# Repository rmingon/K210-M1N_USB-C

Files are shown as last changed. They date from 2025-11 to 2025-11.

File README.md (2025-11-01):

# K210-M1N USB-C Adapter

This repository contains the KiCad 9 project for a compact adapter board that breaks out the **Kendryte K210 M1n** M.2 (Key‑B) module to USB and a minimal set of GPIOs. The board’s USB‑C port is intended primarily for power and UART-based programming through an onboard CH340C USB–serial bridge.

## Hardware Overview

- **Form factor** – Single board implementing the Amphenol MDT320B03001 Key‑B M.2 socket on the top side and a USB‑C receptacle on the edge for direct plug-in to a host.
- **Power** – USB VBUS feeds the CH340C (`+5V`) and is decoupled locally (C9). The board relies on the M1n module’s onboard regulators for `+3.3V` and `+1V8`.
- **USB–UART** – CH340C in SOIC‑16 package with `D+`/`D-` routed to the USB‑C connector and a BOOT/RESET autoprogramming network (R7 to BOOT, R8 to RESET).
- **Status LEDs** – Two LEDs (D1/D2) with current-limiting resistors (R3/R4) monitor `+5V` and `VBUS`.
- **Breakout signals** – Key M.2 pins (IO, SPI0, DVP, etc.) are accessible via the module connector. The schematic uses global labels (`IO4`, `IO5`, …) matching Kendryte’s numbering.

### Board visuals

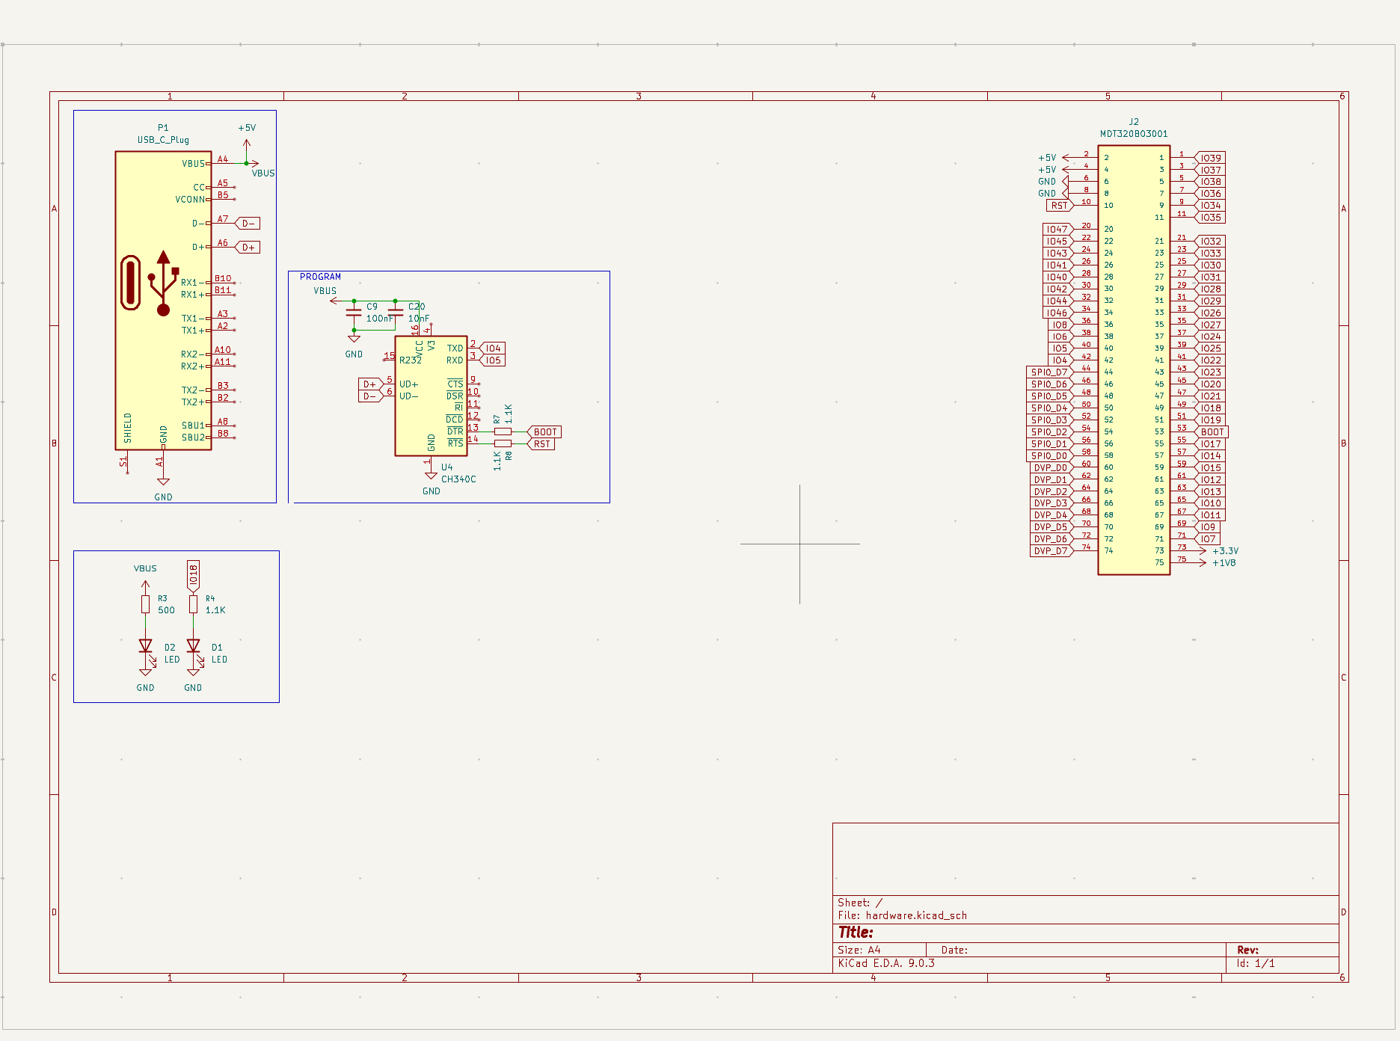
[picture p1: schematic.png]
Schematic overview


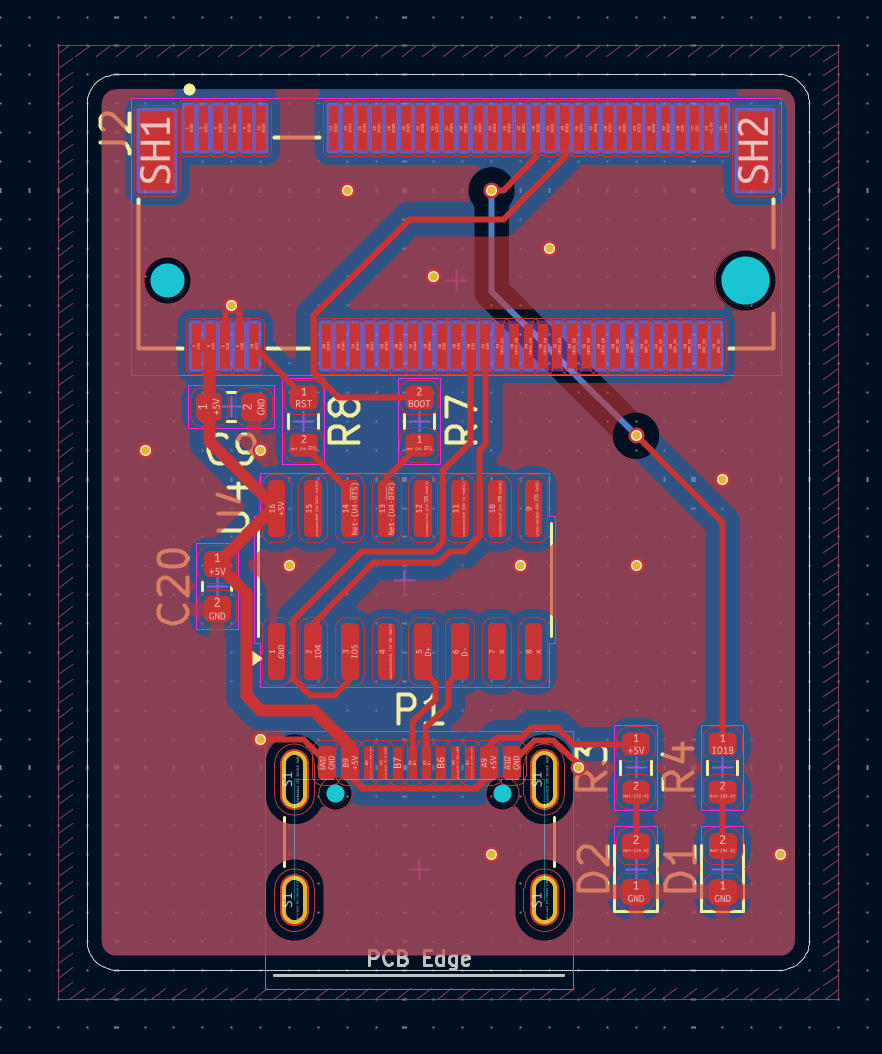
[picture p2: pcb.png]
Layout top view


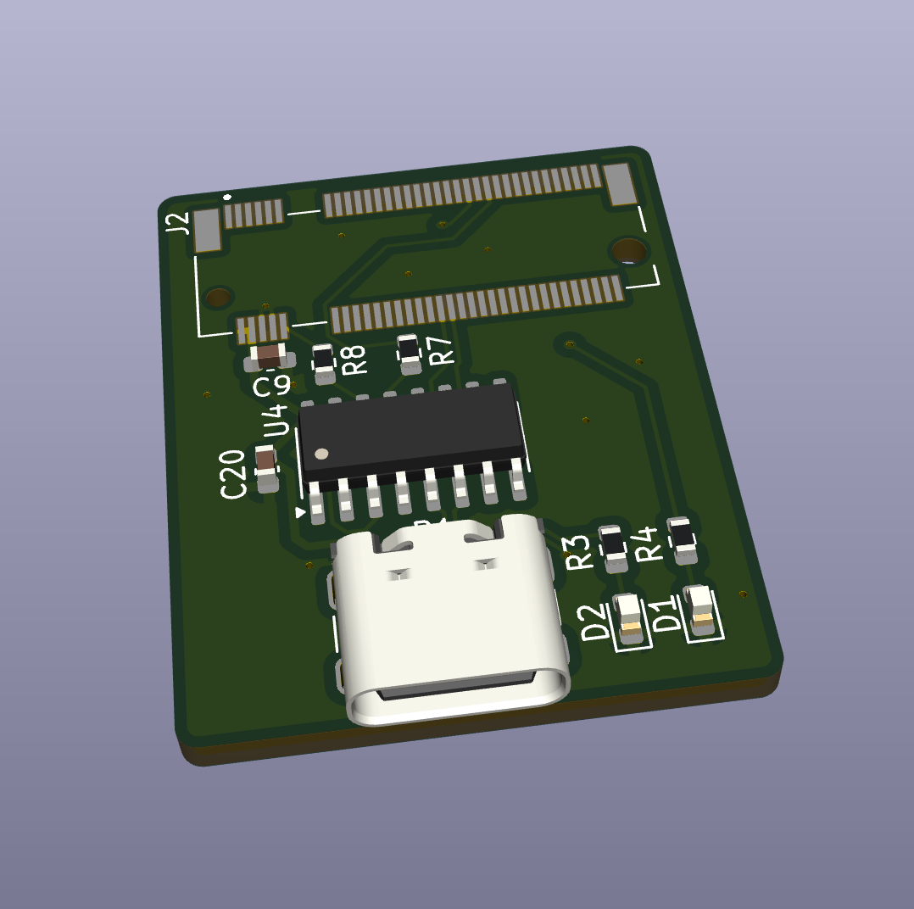
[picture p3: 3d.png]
3D render


## Programming Workflow

- The CH340C exposes a UART for flashing firmware onto the K210 module.
- `~RTS` is routed through R8 to the `RST` net (M.2 pad 10), while `~DTR` drives the `BOOT` net (M.2 pad 53) via R7 to automate the boot sequence used by Kendryte tooling.
- Connect the USB‑C port to your host PC, install CH340 drivers if needed, and use Kendryte’s flashing tools over the enumerated serial port.

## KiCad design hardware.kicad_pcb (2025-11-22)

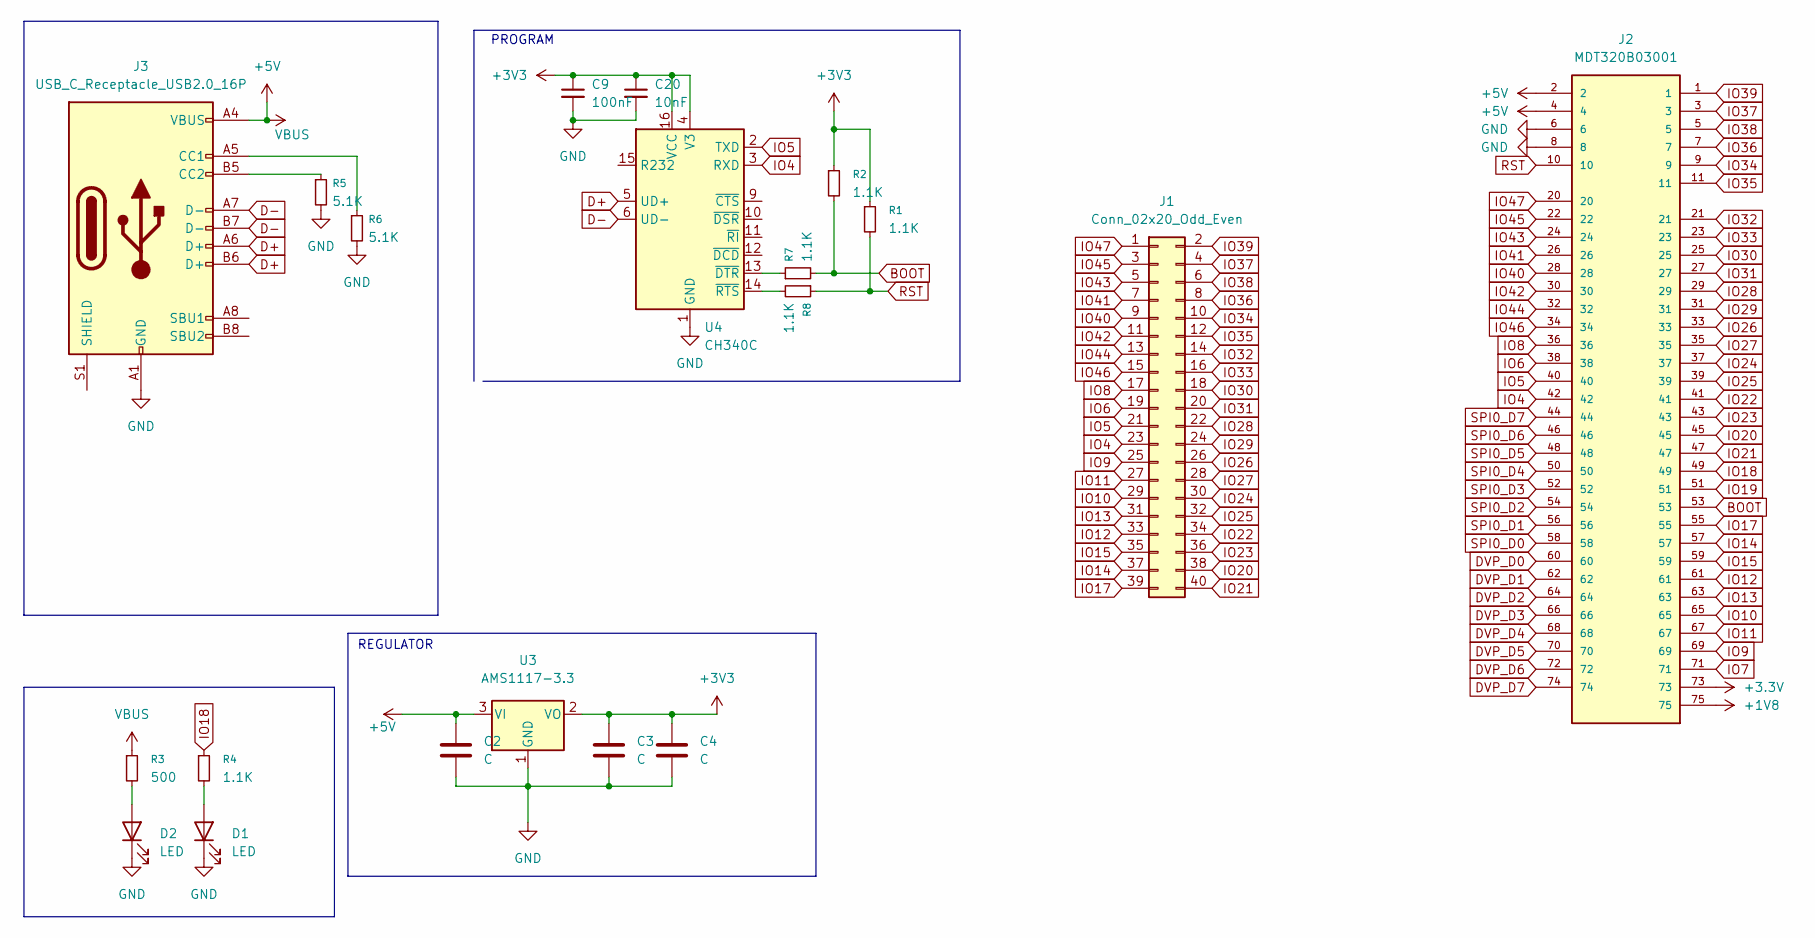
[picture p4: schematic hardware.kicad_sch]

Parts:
C2, C4: C; C_0603_1608Metric; LCSC C30926
C3: C; C_0603_1608Metric; LCSC C19702
C9: 100nF; C_0603_1608Metric
C20: 10nF; C_0603_1608Metric
D1, D2: LED; LED_0603_1608Metric
J1: Conn_02x20_Odd_Even; IDC-Header_2x20_P2.54mm_Horizontal
J2: MDT320B03001; AMPHENOL_MDT320B03001; PARTREV 4
J3: USB_C_Receptacle_USB2.0_16P
R1, R2, R4, R7, R8: 1.1K; R_0603_1608Metric
R3: 500; R_0603_1608Metric
R5, R6: 5.1K; R_0603_1608Metric
U3: AMS1117-3.3; SOT-223-3_TabPin2; LCSC C6186
U4: CH340C; SOIC-16_3.9x9.9mm_P1.27mm

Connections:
+1V8: J2.75
+3.3V: J2.73
+3V3: C3.1, C4.1, C9.1, C20.1, R1.1, R2.1, U3.2 (VO), U4.4 (V3), U4.16 (VCC)
+5V: C2.1, J2.2, J2.4, J3.A4 (VBUS), J3.A9 (VBUS), J3.B4 (VBUS), J3.B9 (VBUS), R3.1, U3.3 (VI)
BOOT: J2.53, R2.2, R7.2
D+: J3.A6 (D+), J3.B6 (D+), U4.5 (UD+)
D-: J3.A7 (D-), J3.B7 (D-), U4.6 (UD-)
DVP_D0: J2.60
DVP_D1: J2.62
DVP_D2: J2.64
DVP_D3: J2.66
DVP_D4: J2.68
DVP_D5: J2.70
DVP_D6: J2.72
DVP_D7: J2.74
GND: C2.2, C3.2, C4.2, C9.2, C20.2, D1.1 (K), D2.1 (K), J2.6, J2.8, J3.A1 (GND), J3.A12 (GND), J3.B1 (GND), J3.B12 (GND), R5.2, R6.2, U3.1 (GND), U4.1 (GND)
IO4: J1.23, J2.42, U4.3 (RXD)
IO5: J1.21, J2.40, U4.2 (TXD)
IO6: J1.19, J2.38
IO7: J2.71
IO8: J1.17, J2.36
IO9: J1.25, J2.69
IO10: J1.29, J2.65
IO11: J1.27, J2.67
IO12: J1.33, J2.61
IO13: J1.31, J2.63
IO14: J1.37, J2.57
IO15: J1.35, J2.59
IO17: J1.39, J2.55
IO18: J2.49, R4.1
IO19: J2.51
IO20: J1.38, J2.45
IO21: J1.40, J2.47
IO22: J1.34, J2.41
IO23: J1.36, J2.43
IO24: J1.30, J2.37
IO25: J1.32, J2.39
IO26: J1.26, J2.33
IO27: J1.28, J2.35
IO28: J1.22, J2.29
IO29: J1.24, J2.31
IO30: J1.18, J2.25
IO31: J1.20, J2.27
IO32: J1.14, J2.21
IO33: J1.16, J2.23
IO34: J1.10, J2.9
IO35: J1.12, J2.11
IO36: J1.8, J2.7
IO37: J1.4, J2.3
IO38: J1.6, J2.5
IO39: J1.2, J2.1
IO40: J1.9, J2.28
IO41: J1.7, J2.26
IO42: J1.11, J2.30
IO43: J1.5, J2.24
IO44: J1.13, J2.32
IO45: J1.3, J2.22
IO46: J1.15, J2.34
IO47: J1.1, J2.20
unnamed: D1.2 (A), R4.2
unnamed: D2.2 (A), R3.2
unnamed: J3.A5 (CC1), R6.1
unnamed: J3.B5 (CC2), R5.1
unnamed: R7.1, U4.13 (~DTR)
unnamed: R8.2, U4.14 (~RTS)
RST: J2.10, R1.2, R8.1
SPI0_D0: J2.58
SPI0_D1: J2.56
SPI0_D2: J2.54
SPI0_D3: J2.52
SPI0_D4: J2.50
SPI0_D5: J2.48
SPI0_D6: J2.46
SPI0_D7: J2.44

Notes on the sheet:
PROGRAM
REGULATOR

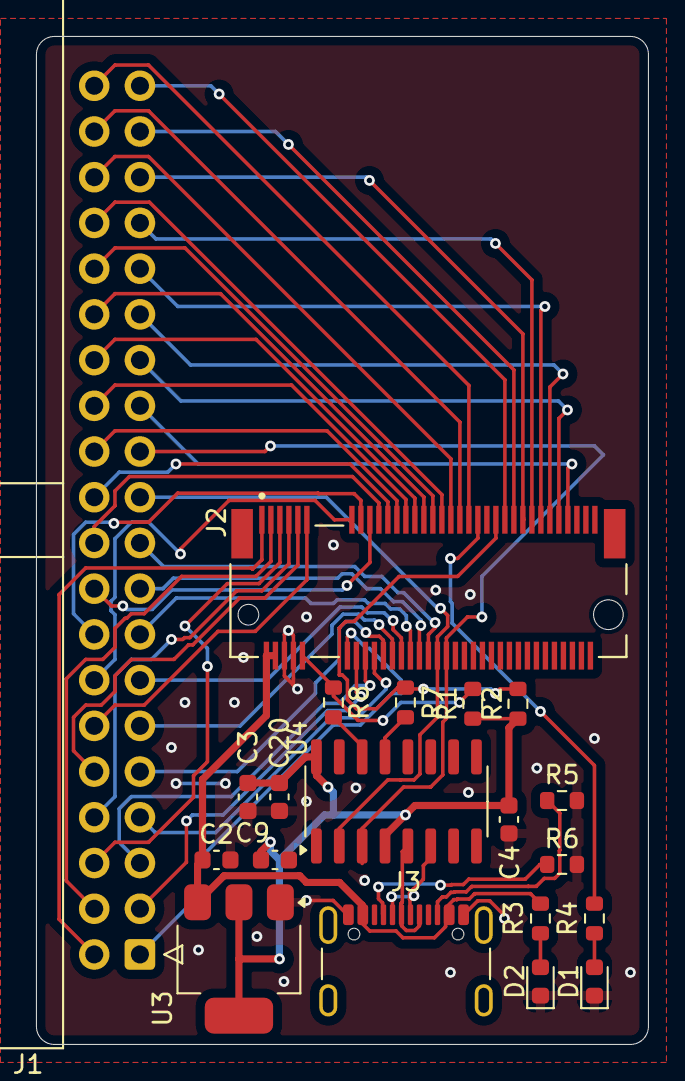
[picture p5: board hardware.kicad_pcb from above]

Board: 2 copper layers, 34.0 x 56.0 mm, 20 parts (0 on the bottom side), 54 nets.

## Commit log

2025-11-01 add wiring + pcb
    [hardware.kicad_pcb, hardware.kicad_sch]
2025-11-01 switch uart wiring
    [hardware.kicad_pcb, hardware.kicad_sch]
2025-11-06 add testing header
    [hardware.kicad_pcb, hardware.kicad_sch]
2025-11-06 add rst/boot pull up
    [hardware.kicad_pcb, hardware.kicad_sch]
2025-11-22 fix usb c wiring
    [hardware.kicad_pcb, hardware.kicad_sch]
